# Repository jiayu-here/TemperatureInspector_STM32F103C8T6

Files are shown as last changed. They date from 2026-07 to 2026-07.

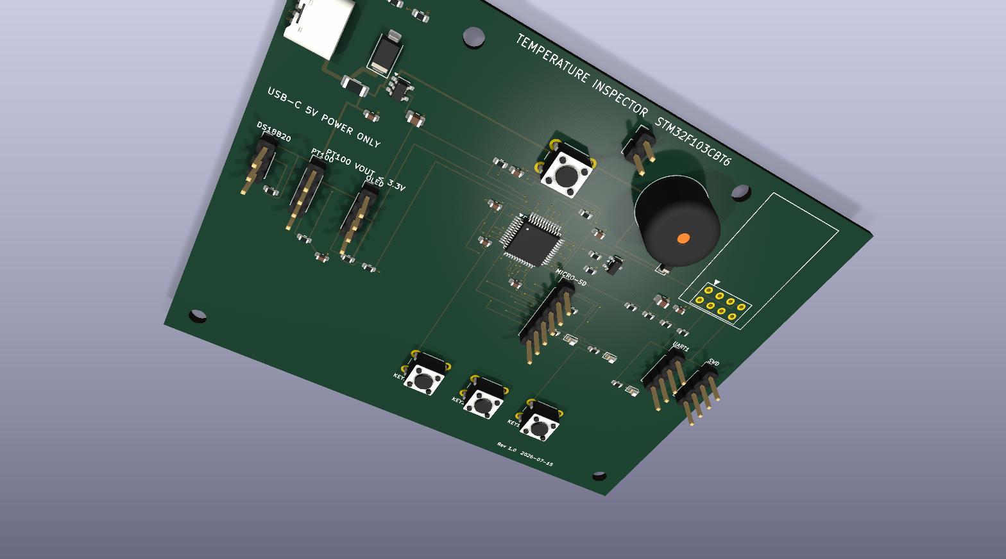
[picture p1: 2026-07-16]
Hardware/KiCad/Preview/PCB_3D_Top.png

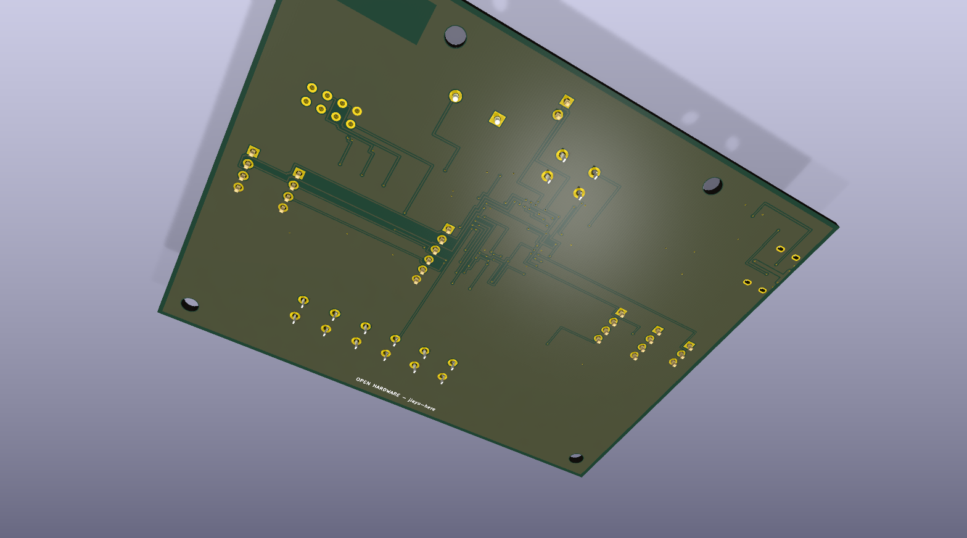
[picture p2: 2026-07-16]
Hardware/KiCad/Preview/PCB_3D_Bottom.png

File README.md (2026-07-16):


# STM32F103C8T6 Temperature Inspector

[English](#english) | [中文](#中文)

This is a temperature-monitoring and alarm project for an STM32F103C8T6 minimum-system board. It integrates DS18B20, PT100 voltage acquisition, OLED, keys, a buzzer, alarm LEDs, SD-card logging through FatFs, serial commands, persistent thresholds, and a reserved ESP-01S cloud-service flow.

## Purpose

The project is designed for embedded temperature-monitoring scenarios. It covers sensor acquisition, data display, alarm decisions, data logging, and serial interaction. It can serve as an STM32 course project, a temperature-acquisition system, a sensor-integration experiment, or an embedded-project portfolio piece.

## Highlights

- Supports both the DS18B20 digital temperature sensor and PT100 analog temperature acquisition.
- OLED displays current temperature, thresholds, alarm status, and system information.
- Supports key configuration, buzzer alarms, and alarm-light indications.
- Uses FatFs to write temperature logs to an SD card.
- Provides serial commands for debugging and parameter inspection.
- Threshold parameters persist across power cycles.
- Reserves an ESP-01S cloud-service flow for future network expansion.
- Supports ST-Link programming and a Keil MDK-compatible project structure.

## Project Entry Points

Main project file:

~~~text
Projects/MDK-ARM/TemperatureInspector_STM32F103C8T6.uvprojx
~~~

Detailed documentation:

~~~text
Docs/工程说明书.md
~~~

Generated HEX file:

~~~text
build_gcc/TemperatureInspector.hex
~~~

## Hardware Design

The repository now includes a complete KiCad 10 schematic and four-layer PCB design. The board uses the pin-compatible `STM32F103CBT6` in LQFP-48, measures 100 mm x 80 mm, and implements the firmware pin map for the sensors, display, storage, alarms, ESP-01S, UART, and SWD interfaces.

- Hardware guide and connector pinout: [`Hardware/KiCad/README_Hardware.md`](Hardware/KiCad/README_Hardware.md)
- KiCad project: `Hardware/KiCad/TemperatureInspector_STM32F103C8T6_Hardware.kicad_pro`
- Manufacturing outputs: `Hardware/KiCad/Manufacturing/`
- Verification reports: `Hardware/KiCad/Verification/` (ERC 0 errors/warnings; DRC 0 violations)
- Ready-to-share archives: `TemperatureInspector_STM32F103C8T6_KiCad_Project.zip` and `TemperatureInspector_STM32F103C8T6_Manufacturing.zip`

## Quick Start

1. Complete wiring using the pin table in Docs/工程说明书.md.
2. Format the SD card as FAT32 and insert it into the SD module.
3. Open Projects/MDK-ARM/TemperatureInspector_STM32F103C8T6.uvprojx in Keil.
4. Connect ST-Link to PA13, PA14, GND, and 3.3 V; keep BOOT0 at 0.
5. Build and download, or directly flash build_gcc/TemperatureInspector.hex.

## Default Parameters

~~~text
Temperature sample period: 15 seconds
Threshold-check period: 15 seconds
SD write period: 15 seconds
DS18B20 default alarm range: below 10 C or above 60 C
PT default alarm range: below 0 C or above 100 C
Cloud service: disabled by default; flow retained in code
Alarm confirmation: alarm after 2 consecutive out-of-range readings
~~~

## Directory Guide

| Directory / file | Purpose |
|---|---|
| Inc/ | Application headers and HAL configuration currently in use |
| Src/ | Application source currently in use |
| Core/ | Synchronized backup of application source and headers |
| Projects/MDK-ARM/ | Keil project |
| Middlewares/Third_Party/FatFs/ | FatFs file-system source |
| Drivers/ | STM32 HAL/CMSIS drivers |
| Docs/ | Project manual, CubeMX configuration, and paper analysis |
| Hardware/KiCad/ | KiCad schematic, PCB, previews, manufacturing files, and ERC/DRC reports |
| build_gcc/ | GCC build output, including flashable HEX |
| TemperatureInspector_STM32F103C8T6.ioc | CubeMX configuration file |

## Suitable Uses

- STM32 embedded-systems course project
- Multi-sensor temperature acquisition and alarm system
- Integrated OLED, SD-card, serial, key, and buzzer experiment
- Keil MDK and STM32 HAL project-structure study

## Notes

- PB3/PB4 are used as keys. Keep debugging in Serial Wire mode; do not enable full JTAG.
- Before powering the board, check power, logic levels, sensor wiring, and SD-card formatting.
- The cloud-service flow is reserved and disabled by default; it can be connected to an actual platform later.

# STM32F103C8T6 温度检测仪

[English](#english) | [中文](#中文)

这是一个基于 STM32F103C8T6 最小系统板的温度检测与报警工程。项目已经接入 DS18B20、PT100 电压采集、OLED、按键、蜂鸣器、报警灯、SD 卡 FatFs 记录、串口命令、阈值掉电保存，以及 ESP-01S 云服务预留流程。

## 项目定位

本项目面向嵌入式温度监测场景，重点覆盖传感器采集、数据显示、报警判断、数据记录和串口交互。它既可以作为 STM32 课程设计，也可以作为温度采集系统、传感器综合实验或嵌入式项目作品展示。

## 功能亮点

- 同时支持 DS18B20 数字温度传感器和 PT100 模拟温度采集。
- OLED 显示当前温度、阈值、报警状态和系统信息。
- 支持按键设置、蜂鸣器报警和报警灯提示。
- 使用 FatFs 将温度记录写入 SD 卡。
- 支持串口命令交互，便于调试和参数查看。
- 阈值参数支持掉电保存。
- 预留 ESP-01S 云服务流程，便于后续扩展联网能力。
- 支持 ST-Link 烧录，工程结构适配 Keil MDK。

## 工程入口

主工程文件：

~~~text
Projects/MDK-ARM/TemperatureInspector_STM32F103C8T6.uvprojx
~~~

详细说明文档：

~~~text
Docs/工程说明书.md
~~~

已生成 HEX：

~~~text
build_gcc/TemperatureInspector.hex
~~~

## 硬件设计

仓库现已包含完整的 KiCad 10 原理图和四层 PCB。板上采用与当前固件引脚兼容的 LQFP-48 `STM32F103CBT6`，板框为 100 mm x 80 mm，已经实现传感器、显示、存储、报警、ESP-01S、串口和 SWD 等接口。

- 硬件说明与接口针序：[`Hardware/KiCad/README_Hardware.md`](Hardware/KiCad/README_Hardware.md)
- KiCad 工程：`Hardware/KiCad/TemperatureInspector_STM32F103C8T6_Hardware.kicad_pro`
- 制造文件：`Hardware/KiCad/Manufacturing/`
- 检查报告：`Hardware/KiCad/Verification/`（ERC 0 错误/警告，DRC 0 违规）
- 可直接交付的压缩包：`TemperatureInspector_STM32F103C8T6_KiCad_Project.zip`、`TemperatureInspector_STM32F103C8T6_Manufacturing.zip`

## 快速使用

1. 按 Docs/工程说明书.md 的引脚表完成接线。
2. 将 SD 卡格式化为 FAT32，并插入 SD 模块。
3. 使用 Keil 打开 Projects/MDK-ARM/TemperatureInspector_STM32F103C8T6.uvprojx。
4. 用 ST-Link 连接 PA13、PA14、GND、3.3V，BOOT0 保持 0。
5. 编译并下载，或直接烧录已生成的 build_gcc/TemperatureInspector.hex。

## 当前默认参数

~~~text
测温周期：15 秒
阈值判断周期：15 秒
SD 写入周期：15 秒
DS18B20 默认报警阈值：低于 10 C 或高于 60 C
PT 默认报警阈值：低于 0 C 或高于 100 C
云服务：默认关闭，代码流程保留
报警确认：连续 2 次超阈值才报警
~~~

## 目录说明

| 目录/文件 | 作用 |
|---|---|
| Inc/ | 当前实际使用的应用头文件和 HAL 配置 |
| Src/ | 当前实际使用的应用源码 |
| Core/ | 同步备份的应用源码/头文件 |
| Projects/MDK-ARM/ | Keil 工程 |
| Middlewares/Third_Party/FatFs/ | FatFs 文件系统源码 |
| Drivers/ | STM32 HAL/CMSIS 驱动 |
| Docs/ | 工程说明、CubeMX 配置、论文分析 |
| Hardware/KiCad/ | KiCad 原理图、PCB、预览图、制造文件和 ERC/DRC 报告 |
| build_gcc/ | GCC 编译输出，含可烧录 HEX |
| TemperatureInspector_STM32F103C8T6.ioc | CubeMX 配置文件 |

## 适用场景

- STM32 嵌入式课程设计。
- 多传感器温度采集与报警系统。
- OLED、SD 卡、串口、按键和蜂鸣器综合实验。
- Keil MDK + STM32 HAL 工程结构学习。

## 注意事项

- PB3/PB4 用作按键，所以调试方式必须保持 Serial Wire，不要启用完整 JTAG。
- 上板前建议先检查供电、电平、传感器接线和 SD 卡格式。
- 云服务流程目前为预留状态，默认关闭，后续可继续接入实际平台。

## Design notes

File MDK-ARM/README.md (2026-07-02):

# Keil Project

Generate the real Keil project from CubeMX:

1. Open `../TemperatureInspector_STM32F103C8T6.ioc`.
2. Set `Toolchain / IDE` to `MDK-ARM`.
3. Click `GENERATE CODE`.
4. CubeMX will create `TemperatureInspector.uvprojx` here.
5. Open it with Keil.

The application code is in:

- `../Core/Inc/app_*.h`
- `../Core/Src/app_*.c`

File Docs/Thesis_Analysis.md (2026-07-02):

# Thesis Analysis And Implementation Mapping

Appendix was not used. The implementation is based on the main thesis body and your confirmed hardware.

## Confirmed Hardware

- Board: STM32F103C8T6 green board
- Display: 4-pin I2C OLED
- WiFi: ESP-01S
- Storage: 6-pin SPI MicroSD module
- PT100 interface: voltage output to STM32 ADC
- Download/debug method: ST-Link SWD
- DS18B20 alarm rule: below 10 C or above 60 C
- PT100 alarm rule: below 0 C or above 100 C

## Thesis Requirements Mapped To Code

- Real-time temperature inspection: `app.c`
- DS18B20 temperature acquisition: `app_ds18b20.c`
- PT100 temperature acquisition through ADC linear formula `temperature = 51.2 * voltage`: `app_pt100.c`
- OLED local display: `app_oled.c`
- LED + buzzer alarm: `app_alarm.c`
- SD card historical data storage: `app_storage.c`
- ESP8266/ESP-01S WiFi remote upload: `app_esp8266.c`
- OneNET MQTT upload: minimal MQTT packet build in `app_esp8266.c`
- Three buttons for independent DS18B20/PT100 threshold adjustment and switching: `app_keys.c`

## Thesis Pins Preserved

- MCU: STM32F103C8T6
- USART1 optional debug UART: PA9 TX, PA10 RX
- ST-Link SWD:
  - SWDIO: PA13
  - SWCLK: PA14
- DS18B20 data pin: PA0
- SD card SPI2:
  - CS: PB12
  - SCK: PB13
  - MISO: PB14
  - MOSI: PB15

## Pins Reassigned For Your Actual Modules

- PT100 voltage input:
  - ADC: PA1 / ADC1_IN1
- Keys:
  - K1: PB3
  - K2: PB4
  - K3: PB5
- OLED I2C1:
  - SCL: PB6
  - SDA: PB7
- ESP-01S USART2:
  - STM32 TX: PA2
  - STM32 RX: PA3
- Buzzer: PB0
- Alarm LED: PB1
- Board LED: PC13

## Calibration Items

- PT100 conversion uses your provided relation: `temperature = 51.2 * voltage`.
- ADC reference is set to 3.3 V in `PT100_ADC_VREF`.
- If measured temperature is off, adjust `PT100_TEMP_PER_VOLT` in `app_config.h`.

## OneNET Items Still Needed

Fill these in `app_config.h` before expecting cloud upload:

- `WIFI_SSID`
- `WIFI_PASSWORD`
- `ONENET_PRODUCT_ID`
- `ONENET_DEVICE_NAME`
- `ONENET_DEVICE_TOKEN`

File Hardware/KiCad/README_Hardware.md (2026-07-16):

# 温度检测仪硬件交付说明

本目录是 `TemperatureInspector_STM32F103C8T6` 的 KiCad 10 硬件工程。主控采用与现有 CubeMX/固件引脚兼容的 `STM32F103CBT6`（LQFP-48）。

- GitHub 工程：<https://github.com/jiayu-here/TemperatureInspector_STM32F103C8T6>
- KiCad 工程：`TemperatureInspector_STM32F103C8T6_Hardware.kicad_pro`
- 原理图：`TemperatureInspector_STM32F103C8T6_Hardware.kicad_sch`
- PCB：`TemperatureInspector_STM32F103C8T6_Hardware.kicad_pcb`
- 原理图 PDF：`Documentation/Schematic.pdf`

## 1. 电路功能

- USB-C 仅作为 5 V 供电输入，不连接 USB 数据线。
- AP2112K-3.3 将 5 V 转换为 3.3 V。
- DS18B20 数字温度采集。
- PT100 模块模拟电压采集，板上提供 1 kΩ + 100 nF RC 滤波。
- OLED、Micro-SD、ESP-01S、UART1、SWD 接口。
- 3 个按键、复位键、有源蜂鸣器、报警灯、运行灯和电源灯。

## 2. 接口针序

### J1 - USB-C 电源

USB-C 5 V 电源输入；CC1/CC2 各使用 5.1 kΩ 下拉。封装选用电源专用的 `GCT USB4125 6P`，与原理图电源引脚一一对应。该接口不支持 USB 数据通信，也不实现 USB-PD 协议。

### J2 - DS18B20

| 引脚 | 信号 | MCU |
|---|---|---|
| 1 | 3V3 | - |
| 2 | DS18B20_DQ | PA0 |
| 3 | GND | - |

### J3 - PT100 模块

| 引脚 | 信号 | MCU/说明 |
|---|---|---|
| 1 | 5V | 模块电源 |
| 2 | 3V3 | 备用 3.3 V 电源 |
| 3 | PT100_RAW/VOUT | 经 1 kΩ + 100 nF 滤波后进入 PA1/ADC1_IN1 |
| 4 | GND | - |

PT100 模块的 VOUT 必须保持在 0-3.3 V 范围内，禁止将 5 V 模拟电压直接送入 PA1。

### J4 - OLED（I2C）

| 引脚 | 信号 | MCU |
|---|---|---|
| 1 | GND | - |
| 2 | 3V3 | - |
| 3 | I2C_SCL | PB6 |
| 4 | I2C_SDA | PB7 |

### J5 - Micro-SD（SPI2）

| 引脚 | 信号 | MCU |
|---|---|---|
| 1 | 3V3 | - |
| 2 | SD_CS | PB12 |
| 3 | SD_SCK | PB13 |
| 4 | SD_MISO | PB14 |
| 5 | SD_MOSI | PB15 |
| 6 | GND | - |

### J6 - 调试串口（USART1）

| 引脚 | 信号 | MCU |
|---|---|---|
| 1 | 3V3 | - |
| 2 | DEBUG_TX | PA9/USART1_TX |
| 3 | DEBUG_RX | PA10/USART1_RX |
| 4 | GND | - |

### J7 - SWD

| 引脚 | 信号 | MCU |
|---|---|---|
| 1 | 3V3 | 目标板电平参考 |
| 2 | SWDIO | PA13 |
| 3 | SWCLK | PA14 |
| 4 | GND | - |

### JP1 - BOOT0

| 引脚 | 信号 |
|---|---|
| 1 | 3V3 |
| 2 | BOOT0 |

正常运行时 JP1 保持断开，R4 将 BOOT0 下拉。需要进入 STM32 ROM Bootloader 时再短接 JP1。

## 3. 固件引脚映射

| 功能 | MCU 引脚 |
|---|---|
| DS18B20 | PA0 |
| PT100 ADC | PA1 |
| ESP-01S UART TX/RX | PA2/PA3（USART2） |
| 调试 UART TX/RX | PA9/PA10（USART1） |
| SWDIO/SWCLK | PA13/PA14 |
| 蜂鸣器 | PB0 |
| 报警灯 | PB1 |
| KEY1/KEY2/KEY3 | PB3/PB4/PB5 |
| OLED SCL/SDA | PB6/PB7（I2C1） |
| SD CS/SCK/MISO/MOSI | PB12/PB13/PB14/PB15（SPI2） |
| 运行灯 | PC13 |

PB3/PB4 已作为按键使用，调试模式必须保持 Serial Wire，不能启用完整 JTAG。

## 4. PCB 与层叠

- 板框：100 mm × 80 mm。
- 板厚：1.6 mm。
- 4 层铜：
  - L1 / F.Cu：元件和信号。
  - L2 / In1.Cu：整面 GND。
  - L3 / In2.Cu：整面 3V3。
  - L4 / B.Cu：信号和 GND 辅助覆铜。
- 4 个 M3 安装孔。
- 推荐制造材料：常规 FR-4；具体介质厚度和铜厚由板厂按其标准 4 层 1.6 mm 叠层确认。

## 5. 设计规则

| 项目 | 设置 |
|---|---|
| 默认/最小线宽 | 0.18 mm |
| 最小铜间距 | 0.15 mm |
| 铜到板边 | 0.30 mm |
| 默认过孔 | 0.40/0.20 mm（外径/钻孔） |
| USB_5V 主干 | 0.60 mm |
| +5V 支路 | 0.30 mm |
| 差分线宽/间距 | 0.18/0.18 mm |
| 差分过孔间距 | 0.18 mm |

USB-C 为纯供电接口，所以当前 PCB 没有实际 USB 差分对；差分规则已保留供后续扩展使用。

## 6. ERC/DRC 验证

最终 KiCad 10.0.4 检查结果：

- ERC：0 Errors，0 Warnings。
- DRC：0 Violations。
- 未连接焊盘：0。
- 封装错误：0。

报告位于：

- `Verification/erc.rpt`
- `Verification/erc.json`
- `Verification/drc.rpt`
- `Verification/drc.json`

## 7. 制造文件

`Manufacturing` 目录包含：

- `Gerber/`：11 个制板层 Gerber 文件和 `.gbrjob` 作业文件。
- `Drill/`：PTH/NPTH Excellon 钻孔文件、钻孔图和钻孔报告。
- `BOM.csv`：物料清单。
- `Component_Positions_All.csv`：全部元件坐标。
- `PickPlace_SMD.csv`：SMD 贴片坐标。

Gerber 使用 KiCad 扩展名 `.gbr`。下单时将 `Gerber` 和 `Drill` 一并交给板厂；贴片时再提供 BOM 和坐标文件。

## 8. 上电与生产注意事项

1. 首次上电前检查 USB 5 V、3.3 V 和 GND 是否短路。
2. 所有外设逻辑电平必须为 3.3 V。
3. PT100 模块输出不得超过 3.3 V。
4. ESP-01S 瞬时电流较大，实际装配时确认 AP2112K、USB 电源和去耦满足峰值电流。
5. ESP-01S 在 3D 预览中没有完整器件模型，只显示焊盘和天线禁布区；不影响 PCB 制造文件。
6. ERC/DRC 通过只代表规则检查通过。批量生产前仍应先打样、实测电源和各接口，再让板厂执行 DFM 检查。

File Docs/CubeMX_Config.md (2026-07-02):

# CubeMX Configuration

Open CubeMX and configure these items for STM32F103C8T6.

## Project Manager

- Project Name: `TemperatureInspector`
- Toolchain / IDE: `MDK-ARM`
- Generate peripheral initialization as pair of `.c/.h` files: optional

## System Core

- SYS:
  - Debug: `Serial Wire`. This disables full JTAG and keeps PB3/PB4 usable for keys.
- RCC:
  - HSE: `Crystal/Ceramic Resonator`
  - LSE: optional. Enable only if your board has 32.768 kHz crystal.
- Clock:
  - HSE: 8 MHz
  - SYSCLK: 72 MHz
  - AHB: 72 MHz
  - APB1: 36 MHz
  - APB2: 72 MHz

## GPIO

- PA0: GPIO output, DS18B20 DQ. The driver switches input/output dynamically.
- PA1: ADC1_IN1, PT100 voltage input. Formula: `temperature = 51.2 * voltage`.
- PB3, PB4, PB5: GPIO input, Pull-up, keys.
- PB0: GPIO output, buzzer.
- PB1: GPIO output, alarm LED.
- PB12: GPIO output, SD CS, default high.
- PC13: GPIO output, board status LED.

## I2C

- I2C1:
  - PB6: SCL
  - PB7: SDA
  - Speed: 100 kHz
  - OLED address: usually `0x3C`

## SPI

## ADC

- ADC1:
  - IN1 on PA1
  - Resolution: 12 bit
  - Continuous Conversion: Disabled
  - External Trigger: Software start
  - Sampling time: 55.5 cycles or longer

- SPI2:
  - PB13: SCK
  - PB14: MISO
  - PB15: MOSI
  - Mode: Full-Duplex Master
  - Data Size: 8 bit
  - CPOL: Low
  - CPHA: 1 Edge
  - NSS: Software
  - Prescaler: start slow, e.g. 256 for init, then faster if your SD driver supports it

## USART

- USART1:
  - PA9 TX, PA10 RX
  - 115200 8N1
  - Optional debug printf UART. Firmware download/debug uses ST-Link SWD, not USART1.

- USART2:
  - PA2 TX, PA3 RX
  - 115200 8N1
  - ESP8266 AT command interface

## Middleware

- FATFS:
  - Enable User-defined or SPI SD card mode depending on CubeMX version.
  - If CubeMX does not provide SPI SD glue automatically, keep FatFs disabled first and use the project without SD logging, then add SD diskio later.

## Required User Code Calls

In generated `main.c`:

```c
#include "app.h"

int main(void)
{
    HAL_Init();
    SystemClock_Config();
    MX_GPIO_Init();
    MX_ADC1_Init();
    MX_I2C1_Init();
    MX_SPI2_Init();
    MX_USART1_UART_Init();
    MX_USART2_UART_Init();
    MX_FATFS_Init();

    App_Init();

    while (1)
    {
        App_Loop();
    }
}
```

## ST-Link Download Settings

In Keil:

- `Options for Target` -> `Debug` -> choose `ST-Link Debugger`.
- `Settings` -> Port: `SW`.
- `Flash Download` -> enable `Reset and Run` if you want the program to start after download.

Hardware wiring:

- ST-Link `SWDIO` -> board `SWDIO / PA13`
- ST-Link `SWCLK` -> board `SWCLK / PA14`
- ST-Link `GND` -> board `GND`
- ST-Link `3.3V` -> board `3.3V` only when you power the board from ST-Link
- Keep `BOOT0 = 0`

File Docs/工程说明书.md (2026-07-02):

# STM32F103C8T6 温度检测报警工程说明书

## 1. 工程概述

本工程用于 STM32F103C8T6 最小系统板，实现双路温度检测、阈值报警、OLED 显示、SD 卡记录、串口调参、阈值掉电保存和云服务预留。

核心功能：

- DS18B20 数字温度采集
- PT100 电压采集，按 `温度 = 51.2 * 电压` 换算
- OLED 实时显示温度、阈值、报警状态、SD 状态、最高/最低温
- 蜂鸣器和 LED 声光报警
- 三个按键调节 DS/PT 各自上下阈值
- 报警可手动静音
- 连续 2 次超阈值才报警，降低误报警
- SD 卡 FatFs 记录 CSV 文件
- SD 写入失败计数显示
- 阈值保存到 STM32 内部 Flash，断电不丢失
- 串口命令读取状态、设置阈值、恢复默认、静音
- ESP-01S 云服务流程保留，默认关闭
- 云上传失败时预留 SD 离线缓存流程

## 2. 硬件清单

| 硬件 | 说明 |
|---|---|
| STM32F103C8T6 最小系统板 | 俗称绿板/蓝板均可，按本文引脚连接 |
| ST-Link | 用 SWD 下载和调试 |
| 0.96 寸 SSD1306 OLED | 4 针 I2C，常见地址 0x3C |
| DS18B20 | 单总线数字温度传感器 |
| PT100 电压转换模块 | 输出电压接 ADC，公式为 `T = 51.2 * V` |
| SD 卡 SPI 模块 | 6 针模块，使用 SPI2 |
| ESP-01S | 云服务预留，默认关闭 |
| 有源蜂鸣器 | 高电平响，接 PB0 |
| LED 或报警灯模块 | 高电平亮，接 PB1 |
| 3 个按键 | 低电平按下，使用内部上拉 |

## 3. 完整引脚表

| 模块 | 模块信号 | STM32 引脚 | STM32 功能 | 说明 |
|---|---|---|---|---|
| DS18B20 | DQ | PA0 | GPIO | 需要 4.7k 上拉到 3.3V |
| PT100 电压模块 | AO/VOUT | PA1 | ADC1_IN1 | 输入电压不能超过 3.3V |
| ESP-01S | RX | PA2 | USART2_TX | STM32 发给 ESP |
| ESP-01S | TX | PA3 | USART2_RX | ESP 发给 STM32 |
| 蜂鸣器 | IN | PB0 | GPIO Output | 高电平响 |
| 报警灯 | IN | PB1 | GPIO Output | 高电平亮 |
| 按键 1 | K1 | PB3 | GPIO Input Pull-up | 当前阈值减小 |
| 按键 2 | K2 | PB4 | GPIO Input Pull-up | 当前阈值增大 |
| 按键 3 | K3 | PB5 | GPIO Input Pull-up | 切换当前阈值 |
| OLED | SCL | PB6 | I2C1_SCL | I2C 时钟 |
| OLED | SDA | PB7 | I2C1_SDA | I2C 数据 |
| SD 卡模块 | CS | PB12 | GPIO Output | 片选，默认高 |
| SD 卡模块 | SCK | PB13 | SPI2_SCK | SPI 时钟 |
| SD 卡模块 | MISO/DO | PB14 | SPI2_MISO | SD 到 STM32 |
| SD 卡模块 | MOSI/DI | PB15 | SPI2_MOSI | STM32 到 SD |
| 串口调试 | TX | PA9 | USART1_TX | 连接 USB-TTL RX |
| 串口调试 | RX | PA10 | USART1_RX | 连接 USB-TTL TX |
| ST-Link | SWDIO | PA13 | SWDIO | 下载/调试 |
| ST-Link | SWCLK | PA14 | SWCLK | 下载/调试 |
| 板载 LED | LED | PC13 | GPIO Output | 心跳灯 |

注意：

- PB3/PB4 默认属于 JTAG 引脚，本工程已关闭 JTAG，只保留 SWD。因此 CubeMX/Keil 中 Debug 必须选 `Serial Wire`。
- 所有模块必须共地。
- PT100 模块输出必须确认不超过 3.3V，否则会损坏 STM32 ADC。
- ESP-01S 必须使用 3.3V 供电，电流能力要足够。

## 4. OLED 显示说明

正常运行时 OLED 8 行含义如下：

```text
DS:+025.3C
PT:+051.2C
DSL:010 DSH:060
PTL:000 PTH:100
DA:0 PA:0 AL:0
M:0 DSL SD:1 E:0
D:024/026
P:050/053
```

逐行解释：

| 行 | 示例 | 含义 |
|---|---|---|
| 1 | `DS:+025.3C` | DS18B20 当前温度；`DS:ERR` 表示读取失败 |
| 2 | `PT:+051.2C` | PT 电压换算温度 |
| 3 | `DSL:010 DSH:060` | DS18B20 低阈值/高阈值 |
| 4 | `PTL:000 PTH:100` | PT 低阈值/高阈值 |
| 5 | `DA:0 PA:0 AL:0` | DS 报警/PT 报警/总报警 |
| 6 | `M:0 DSL SD:1 E:0` | 静音状态/当前调节项/SD 状态/SD 错误次数 |
| 7 | `D:024/026` | DS18B20 开机后的最低/最高温 |
| 8 | `P:050/053` | PT 开机后的最低/最高温 |

状态含义：

- `DA:1`：DS18B20 连续 2 次超阈值
- `PA:1`：PT 连续 2 次超阈值
- `AL:1`：总报警成立
- `M:1`：报警已手动静音
- `SD:1`：SD 卡正常
- `SD:0`：SD 卡未挂载或写入失败
- `E:n`：SD 写入失败次数
- `WF:0`：云服务关闭或未连接；当前默认关闭

OLED 采用“内容变化才刷新”的方式，正常不会快速闪屏。

## 5. 按键使用说明

三个按键均为低电平按下。

| 操作 | 功能 |
|---|---|
| `KEY3` 短按 | 切换当前调节项：`DSL -> DSH -> PTL -> PTH` |
| `KEY1` 短按 | 当前阈值减小 1 C |
| `KEY2` 短按 | 当前阈值增大 1 C |
| `KEY1` 长按 | 超过 1 秒后连续减小，每 250 ms 一次 |
| `KEY2` 长按 | 超过 1 秒后连续增大，每 250 ms 一次 |
| `KEY1 + KEY2` 同时按 | 报警静音/恢复 |

阈值说明：

- `DSL`：DS18B20 低温报警阈值
- `DSH`：DS18B20 高温报警阈值
- `PTL`：PT 低温报警阈值
- `PTH`：PT 高温报警阈值

阈值改动后会自动保存到 STM32 内部 Flash，断电后仍然保留。

## 6. 串口命令说明

USART1 用于串口调试：

- PA9：STM32 TX，接 USB-TTL RX
- PA10：STM32 RX，接 USB-TTL TX
- 波特率：115200
- 数据格式：8N1

支持命令：

```text
GET
SET DSL 10
SET DSH 60
SET PTL 0
SET PTH 100
RESET
MUTE
```

命令说明：

| 命令 | 功能 |
|---|---|
| `GET` | 查看当前阈值、SD 状态、报警状态 |
| `SET DSL 10` | 设置 DS18B20 低阈值为 10 C |
| `SET DSH 60` | 设置 DS18B20 高阈值为 60 C |
| `SET PTL 0` | 设置 PT 低阈值为 0 C |
| `SET PTH 100` | 设置 PT 高阈值为 100 C |
| `RESET` | 恢复默认阈值并保存 |
| `MUTE` | 报警静音/恢复 |

## 7. SD 卡记录说明

SD 卡使用 SPI2 + FatFs。

接线：

| SD 模块 | STM32 |
|---|---|
| CS | PB12 |
| SCK | PB13 |
| MISO/DO | PB14 |
| MOSI/DI | PB15 |
| VCC | 3.3V |
| GND | GND |

使用要求：

- SD 卡建议格式化为 FAT32。
- 上电前插入 SD 卡。
- 若 OLED 显示 `SD:0`，检查接线、电源、格式化和卡座接触。

日志文件：

```text
temp_log.csv
```

首次创建文件时会自动写表头：

```text
time_ms,ds18b20,pt100,ds_low,ds_high,pt_low,pt_high,ds_alarm,pt_alarm,alarm
```

记录周期：15 秒。

云服务离线缓存文件：

```text
cloud_cache.csv
```

当前云服务默认关闭，所以正常不会生成该文件。以后开启云服务后，如果上传失败，会把待上传数据缓存到该文件。

## 8. 报警逻辑

采样周期：15 秒。

判断逻辑：

1. 每 15 秒读取 DS18B20 和 PT。
2. 判断是否低于低阈值或高于高阈值。
3. 同一路温度连续 2 次超阈值，才认为报警成立。
4. 任一路报警成立，总报警 `AL` 置 1。
5. 总报警成立且未静音时，蜂鸣器和报警灯按节奏闪烁/鸣响。
6. 温度恢复正常后，报警和静音状态自动清除。

## 9. 云服务说明

ESP-01S 云服务代码已经保留，但默认关闭：

```c
#define APP_ENABLE_WIFI 0
```

配置文件：

```text
Inc/app_config.h
```

如需开启，需要填写：

```c
WIFI_SSID
WIFI_PASSWORD
ONENET_PRODUCT_ID
ONENET_DEVICE_NAME
ONENET_DEVICE_TOKEN
```

然后把：

```c
#define APP_ENABLE_WIFI 0
```

改成：

```c
#define APP_ENABLE_WIFI 1
```

云服务流程：

1. `ESP8266_Init()` 初始化 ESP-01S。
2. 连接 WiFi。
3. 连接 OneNET MQTT。
4. 每 15 秒调用 `ESP8266_Upload()` 上传温度和报警状态。
5. 如果上传失败，写入 SD 卡 `cloud_cache.csv`。
6. 网络恢复并上传成功后，清除缓存文件。

注意：ESP-01S 必须使用稳定 3.3V 电源，不建议直接从普通 USB-TTL 小电流 3.3V 脚供电。

## 10. CubeMX 配置要点

MCU：`STM32F103C8T6`

System Core：

- SYS Debug：`Serial Wire`
- RCC：HSE 8 MHz
- SYSCLK：72 MHz

外设：

- ADC1_IN1：PA1
- I2C1：PB6/PB7，100 kHz
- SPI2：PB13/PB14/PB15，Master，8 bit，CPOL Low，CPHA 1 Edge，NSS Software
- USART1：PA9/PA10，115200
- USART2：PA2/PA3，115200
- GPIO：按本文引脚表配置

FatFs：

- 本工程已经内置 FatFs 和 SPI SD 底层驱动。
- 不依赖 CubeMX 自动生成 `fatfs.c`。
- 重新生成 CubeMX 代码后，需要保留 `Middlewares/Third_Party/FatFs` 和 `Src/app_storage.c`。

## 11. Keil 使用说明

工程文件：

```text
Projects/MDK-ARM/TemperatureInspector_STM32F103C8T6.uvprojx
```

Keil 设置：

- Device：STM32F103C8
- Debug：ST-Link Debugger
- Port：SW
- Flash Download：Reset and Run

如果 Keil 弹出：

```text
Project File has been modified externally, Reload?
```

选择 `Yes`。

## 12. VS Code 使用说明

VS Code 主要用于看代码和编辑代码。

建议打开整个工程根目录，例如本项目文件夹：

```text
TemperatureInspector_STM32F103C8T6
```

主要看这些文件：

| 文件 | 作用 |
|---|---|
| `Inc/app_config.h` | 引脚、周期、默认阈值、WiFi 配置 |
| `Src/app.c` | 主业务逻辑 |
| `Src/app_oled.c` | OLED 显示 |
| `Src/app_storage.c` | SD 卡记录 |
| `Src/app_ds18b20.c` | DS18B20 驱动 |
| `Src/app_pt100.c` | PT 温度换算 |
| `Src/app_esp8266.c` | ESP-01S/OneNET 流程 |
| `Src/app_settings.c` | 阈值 Flash 保存 |

## 13. ST-Link 烧录说明

接线：

| ST-Link | STM32 |
|---|---|
| SWDIO | PA13/SWDIO |
| SWCLK | PA14/SWCLK |
| GND | GND |
| 3.3V | 3.3V，可选，取决于供电方式 |

BOOT0 保持 `0`。

可烧录文件：

```text
build_gcc/TemperatureInspector.hex
```

也可以在 Keil 中编译后下载。

## 14. 工程目录说明

| 路径 | 说明 |
|---|---|
| `Inc/` | 当前实际使用的头文件 |
| `Src/` | 当前实际使用的源文件 |
| `Core/` | 同步备份代码 |
| `Drivers/` | STM32 HAL/CMSIS 驱动 |
| `Middlewares/Third_Party/FatFs/` | FatFs 文件系统 |
| `Projects/MDK-ARM/` | Keil 工程 |
| `Docs/` | 文档 |
| `build_gcc/` | GCC 输出，含 HEX |
| `TemperatureInspector_STM32F103C8T6.ioc` | CubeMX 工程 |

## 15. 常见问题

### OLED 不显示

- 检查 OLED 地址是否为 0x3C。
- 检查 PB6/PB7 是否接反。
- 检查 OLED 电源和 GND。

### DS 显示 ERR

- 检查 PA0 接线。
- 检查 DS18B20 是否有 4.7k 上拉到 3.3V。
- 检查 DS18B20 电源方向。

### PT 温度不对

- 用万用表测 PA1 输入电压。
- 当前公式是 `T = 51.2 * V`。
- 例如 PA1 是 1.00V，则显示约 51.2 C。
- PA1 电压不能超过 3.3V。

### SD:0 或 E 变大

- SD 卡格式化为 FAT32。
- 检查 PB12/PB13/PB14/PB15。
- 检查 SD 模块是否支持 3.3V 逻辑。
- 重新插卡后按复位。

### 蜂鸣器一直响

- 查看 OLED 的 `DA/PA/AL`。
- 若 `AL:1`，说明连续 2 次超阈值。
- 可按 `KEY1 + KEY2` 静音。
- 检查阈值是否设置过低/过高。

### 按键没反应

- 按键一端接 GPIO，一端接 GND。
- 工程使用内部上拉，所以按下应为低电平。
- PB3/PB4 需要关闭 JTAG，只保留 SWD。

## 16. 交付状态

本工程已经完成：

- 源码整理
- 关键源码中文注释
- FatFs/SD 底层驱动接入
- Keil 工程源文件加入
- ST-Link 烧录验证
- OLED 内容变化才刷新
- 阈值 Flash 保存
- 串口命令
- 开机自检
- SD CSV 记录
- 云服务预留流程

别人拿到工程后，按本文接线并烧录 `build_gcc/TemperatureInspector.hex` 即可运行。

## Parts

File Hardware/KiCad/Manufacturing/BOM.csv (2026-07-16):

Reference | Value | Footprint | Quantity
BZ1 | 5V ACTIVE BUZZER | Buzzer_Beeper:Buzzer_12x9.5RM7.6 | 1
C1 | 1u | Capacitor_SMD:C_0603_1608Metric | 1
C2 | 4.7u | Capacitor_SMD:C_0805_2012Metric | 1
C3-C5,C7,C8,C10 | 100n | Capacitor_SMD:C_0603_1608Metric | 6
C6 | 1u VDDA | Capacitor_SMD:C_0603_1608Metric | 1
C9 | 10u | Capacitor_SMD:C_0805_2012Metric | 1
D1 | SMBJ5.0A | Diode_SMD:D_SMA | 1
D2 | 1N4148 | Diode_SMD:D_SOD-123 | 1
D3 | ALARM RED | LED_SMD:LED_0603_1608Metric | 1
D4 | HEARTBEAT GREEN | LED_SMD:LED_0603_1608Metric | 1
D5 | POWER GREEN | LED_SMD:LED_0603_1608Metric | 1
F1 | 1A PTC | Fuse:Fuse_1206_3216Metric | 1
J1 | USB-C 5V POWER ONLY | Connector_USB:USB_C_Receptacle_GCT_USB4125-xx-x_6P_TopMnt_Horizontal | 1
J2 | DS18B20: 3V3,DQ,GND | Connector_PinHeader_2.54mm:PinHeader_1x03_P2.54mm_Vertical | 1
J3 | PT100: 5V,3V3,VOUT,GND | Connector_PinHeader_2.54mm:PinHeader_1x04_P2.54mm_Vertical | 1
J4 | OLED: GND,3V3,SCL,SDA | Connector_PinHeader_2.54mm:PinHeader_1x04_P2.54mm_Vertical | 1
J5 | SD: 3V3,CS,SCK,MISO,MOSI,GND | Connector_PinHeader_2.54mm:PinHeader_1x06_P2.54mm_Vertical | 1
J6 | UART1: 3V3,TX,RX,GND | Connector_PinHeader_2.54mm:PinHeader_1x04_P2.54mm_Vertical | 1
J7 | SWD: 3V3,SWDIO,SWCLK,GND | Connector_PinHeader_2.54mm:PinHeader_1x04_P2.54mm_Vertical | 1
JP1 | BOOT0 | Connector_PinHeader_2.54mm:PinHeader_1x02_P2.54mm_Vertical | 1
Q1 | MMBT3904 | Package_TO_SOT_SMD:SOT-23 | 1
R1,R2 | 5.1k | Resistor_SMD:R_0603_1608Metric | 2
R3,R4,R9-R13 | 10k | Resistor_SMD:R_0603_1608Metric | 7
R5,R7,R8 | 4.7k | Resistor_SMD:R_0603_1608Metric | 3
R6,R14,R16,R18 | 1k | Resistor_SMD:R_0603_1608Metric | 4
R15 | 100k | Resistor_SMD:R_0603_1608Metric | 1
R17 | 2.2k | Resistor_SMD:R_0603_1608Metric | 1
SW1 | KEY1 | Button_Switch_THT:SW_PUSH_6mm | 1
SW2 | KEY2 | Button_Switch_THT:SW_PUSH_6mm | 1
SW3 | KEY3 | Button_Switch_THT:SW_PUSH_6mm | 1
SW4 | RESET | Button_Switch_THT:SW_PUSH_6mm | 1
U1 | STM32F103CBT6 | Package_QFP:LQFP-48_7x7mm_P0.5mm | 1
U2 | AP2112K-3.3 | Package_TO_SOT_SMD:SOT-23-5 | 1
U3 | ESP-01S | RF_Module:ESP-01 | 1

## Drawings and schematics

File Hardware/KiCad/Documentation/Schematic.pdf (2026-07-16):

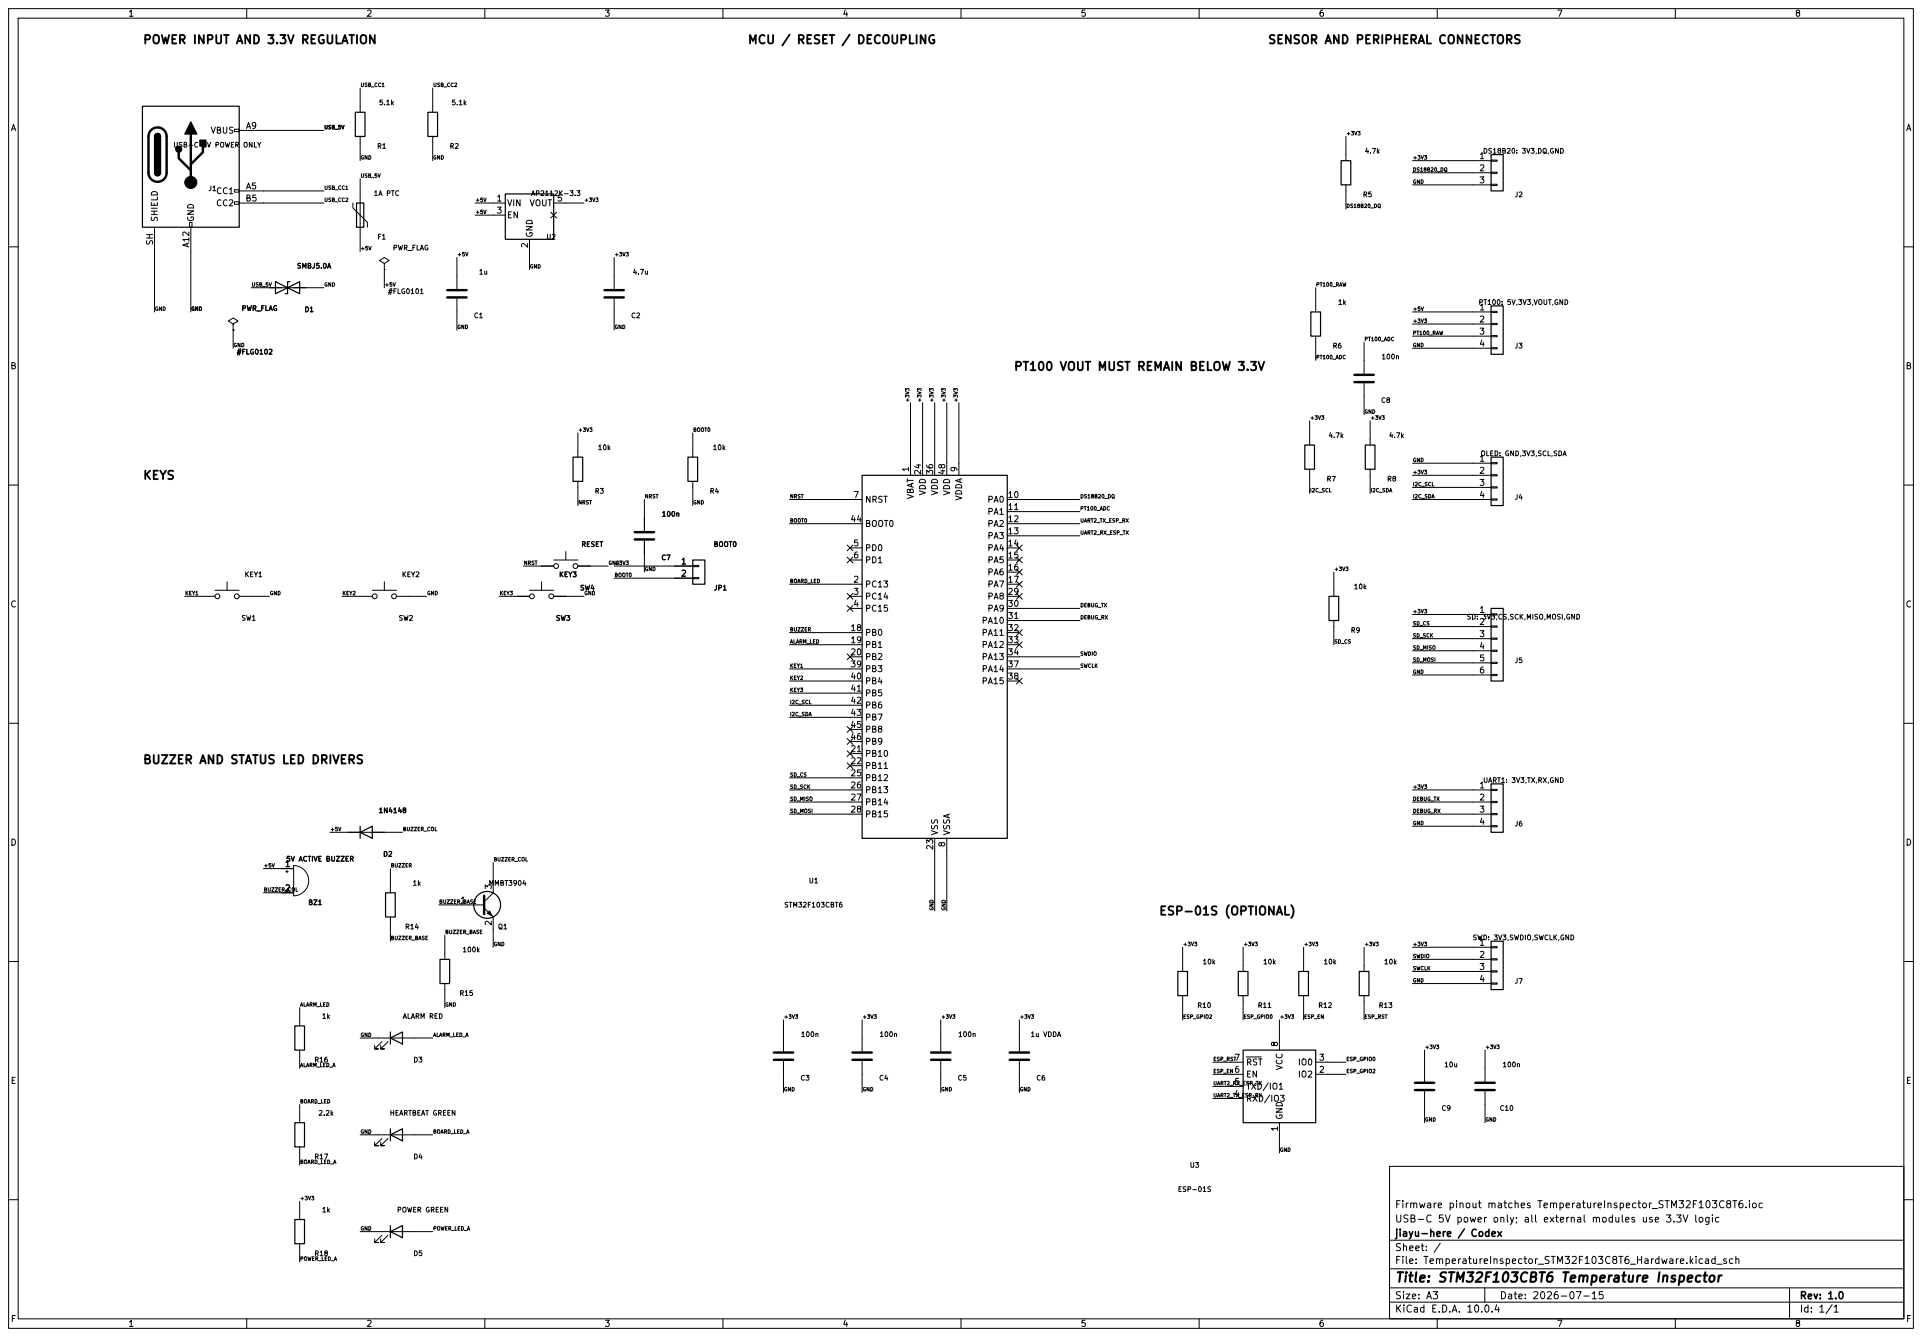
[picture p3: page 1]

POWER INPUT AND 3.3V REGULATION

PT100 VOUT MUST REMAIN BELOW 3.3V

SD: 3V3,CS,SCK,MISO,MOSI,GND 1

BUZZER AND STATUS LED DRIVERS

Firmware pinout matches TemperatureInspector_STM32F103C8T6.ioc
USB-C 5V power only; all external modules use 3.3V logic
jiayu-here / Codex
Sheet: /
File: TemperatureInspector_STM32F103C8T6_Hardware.kicad_sch
Title: STM32F103CBT6 Temperature Inspector

Size: A3 | Rev: 1.0 | F Date: 2026-07-15
KiCad E.D.A. 10.0.4 | Id: 1/1

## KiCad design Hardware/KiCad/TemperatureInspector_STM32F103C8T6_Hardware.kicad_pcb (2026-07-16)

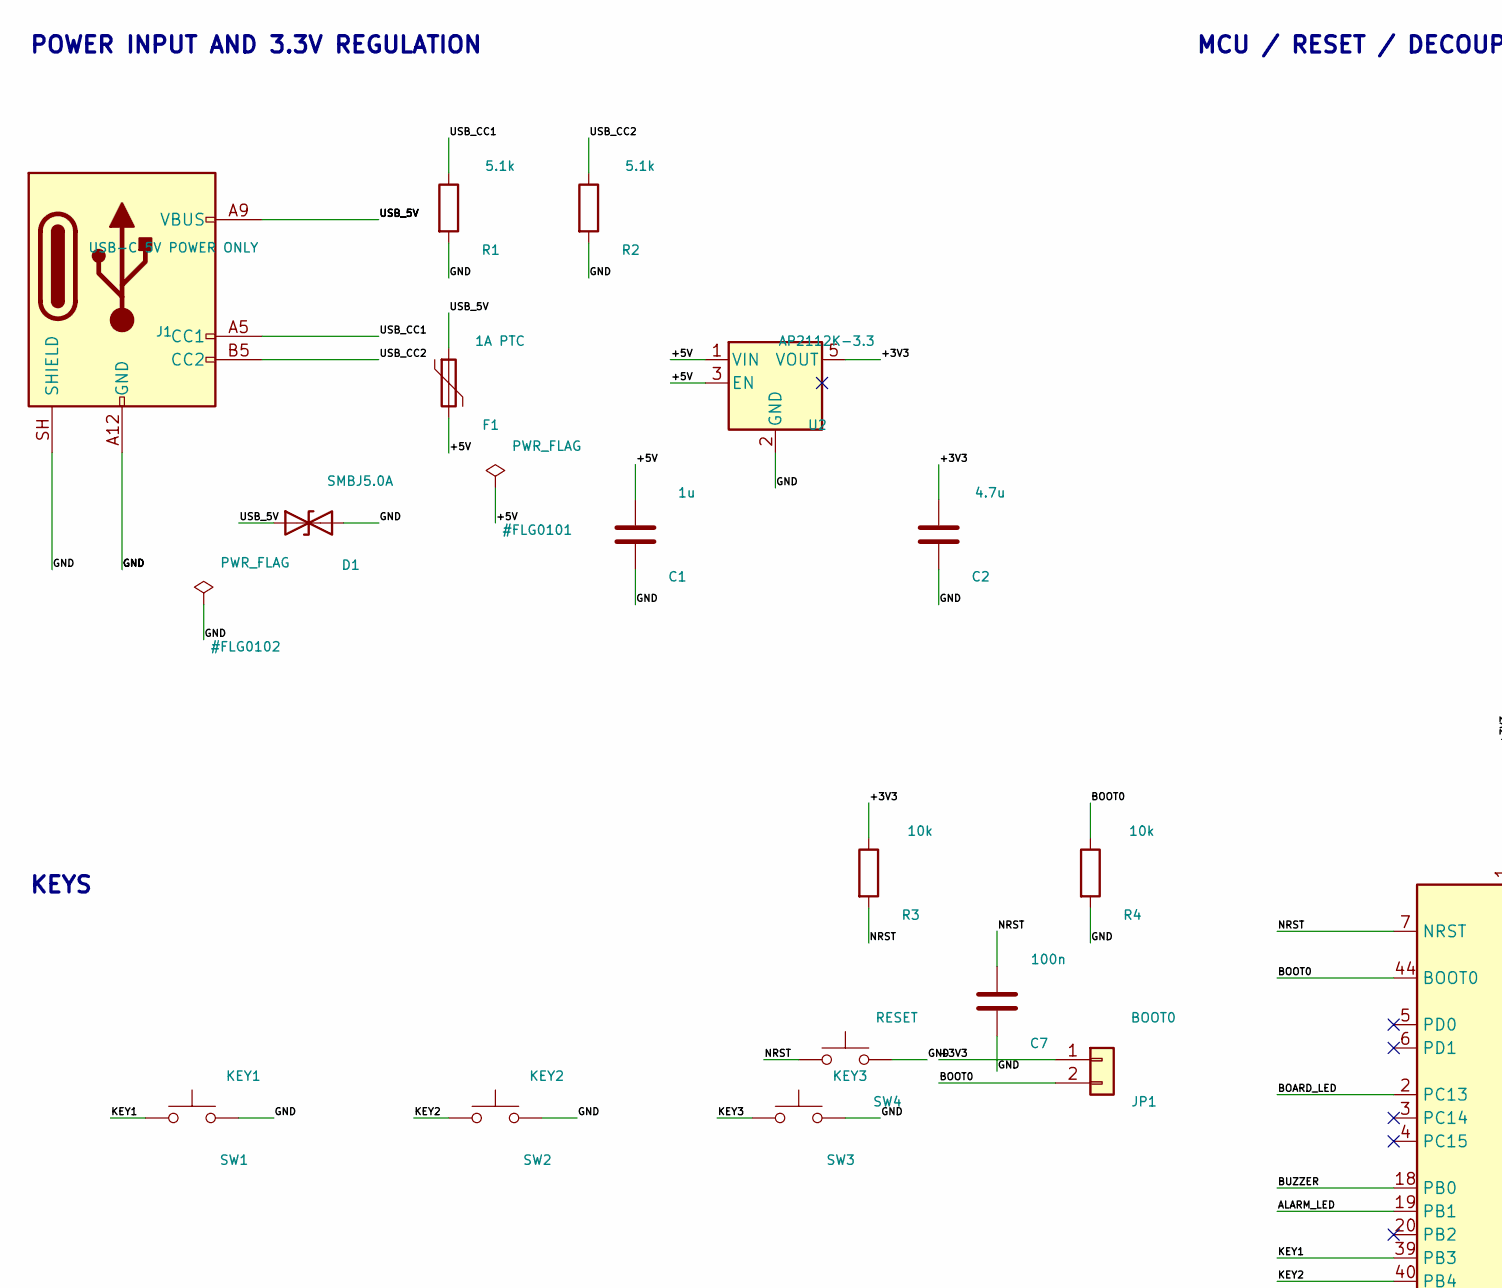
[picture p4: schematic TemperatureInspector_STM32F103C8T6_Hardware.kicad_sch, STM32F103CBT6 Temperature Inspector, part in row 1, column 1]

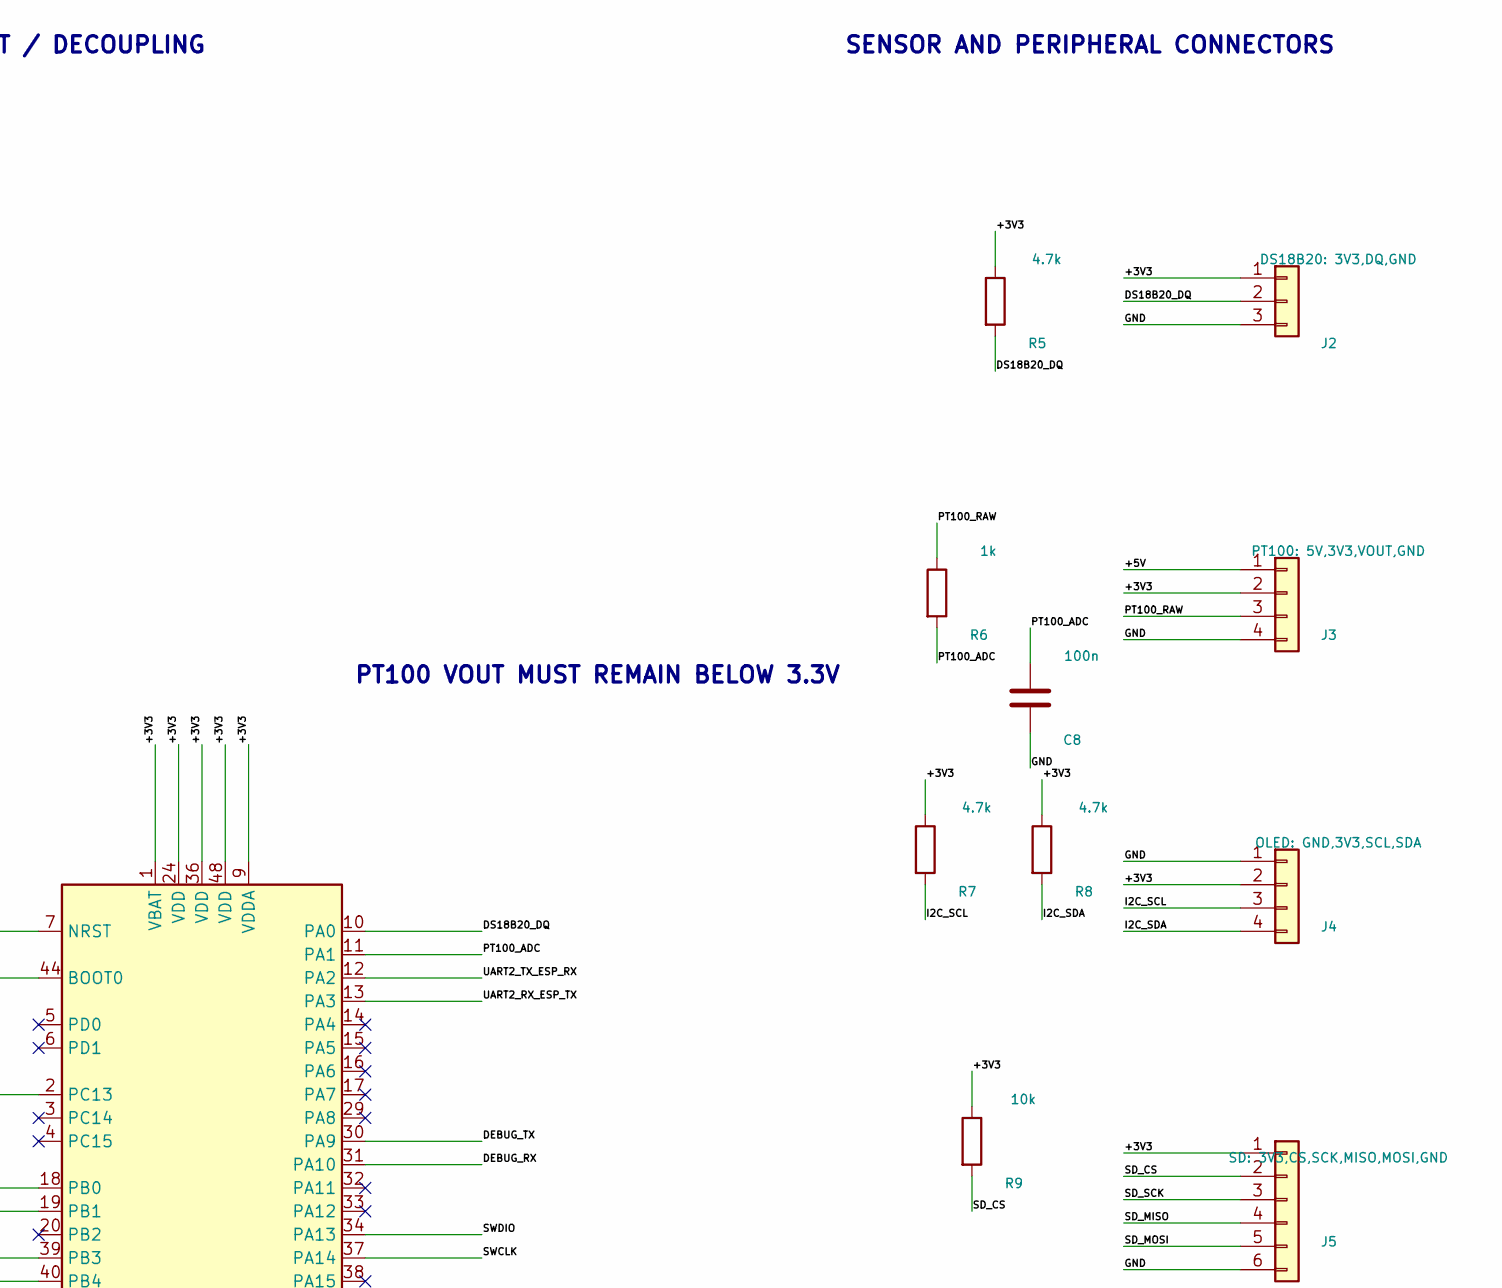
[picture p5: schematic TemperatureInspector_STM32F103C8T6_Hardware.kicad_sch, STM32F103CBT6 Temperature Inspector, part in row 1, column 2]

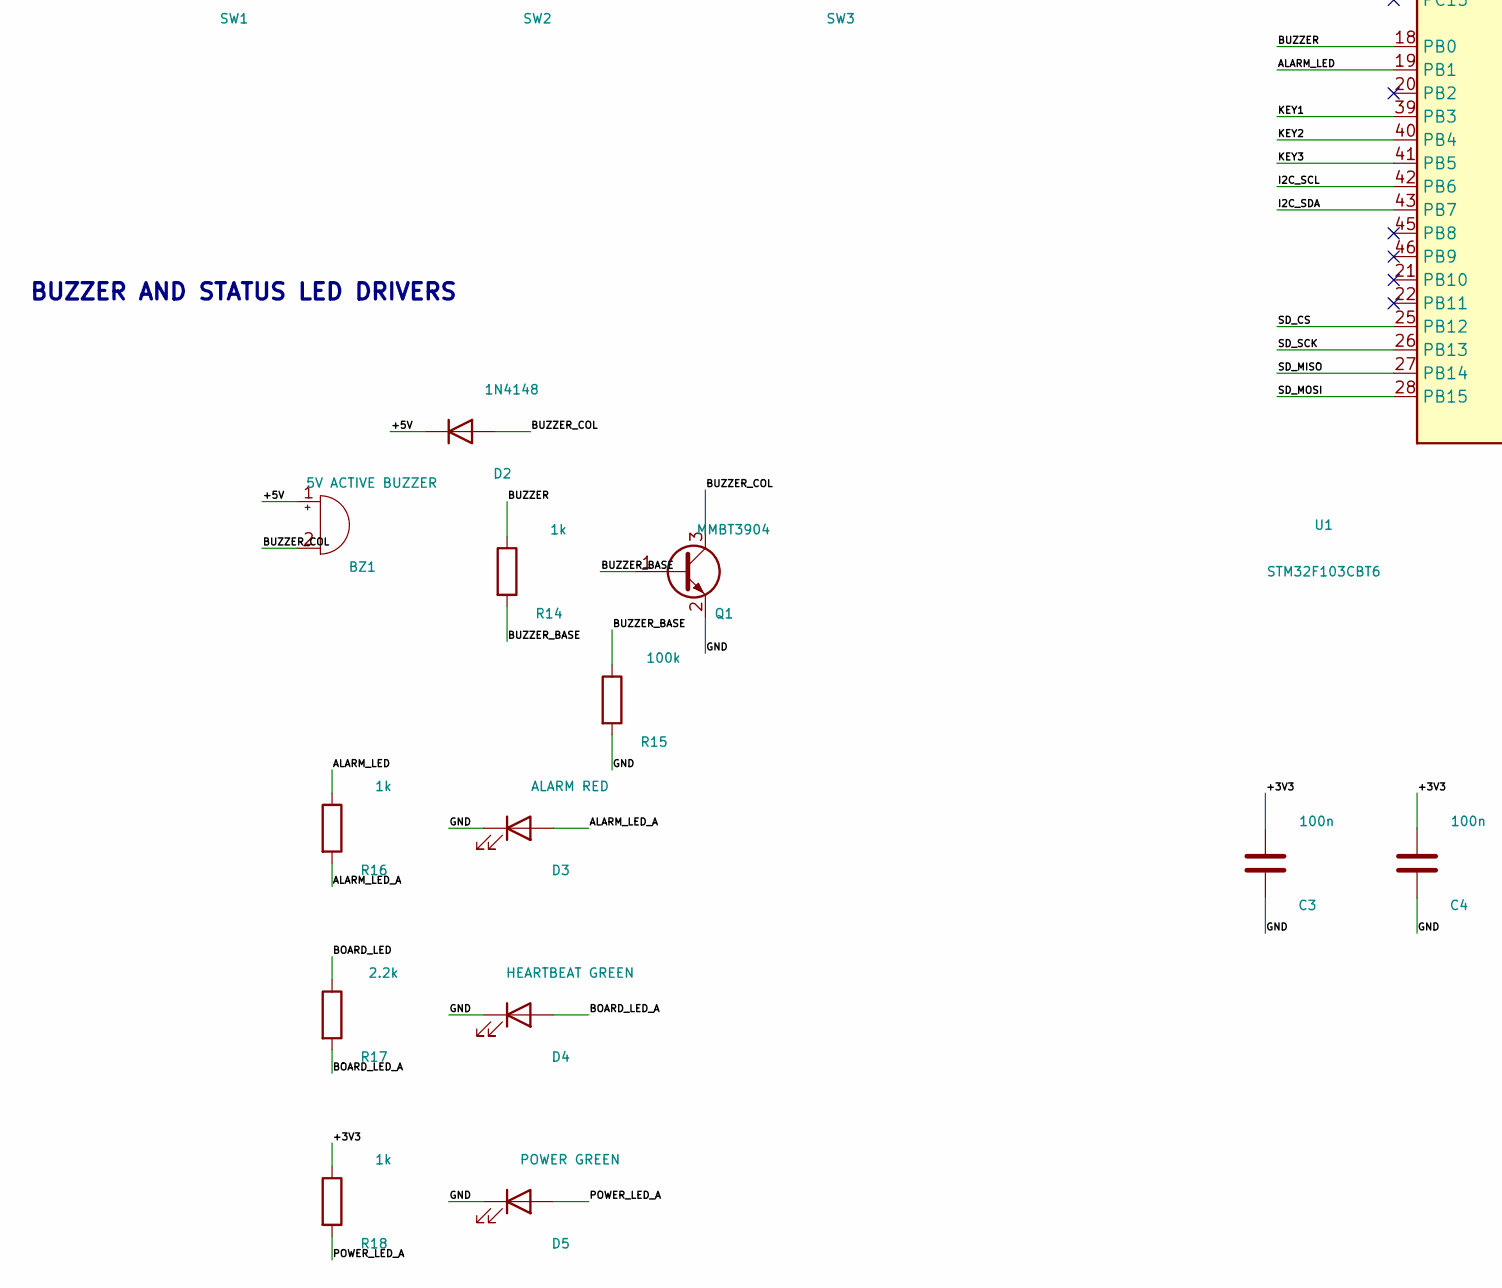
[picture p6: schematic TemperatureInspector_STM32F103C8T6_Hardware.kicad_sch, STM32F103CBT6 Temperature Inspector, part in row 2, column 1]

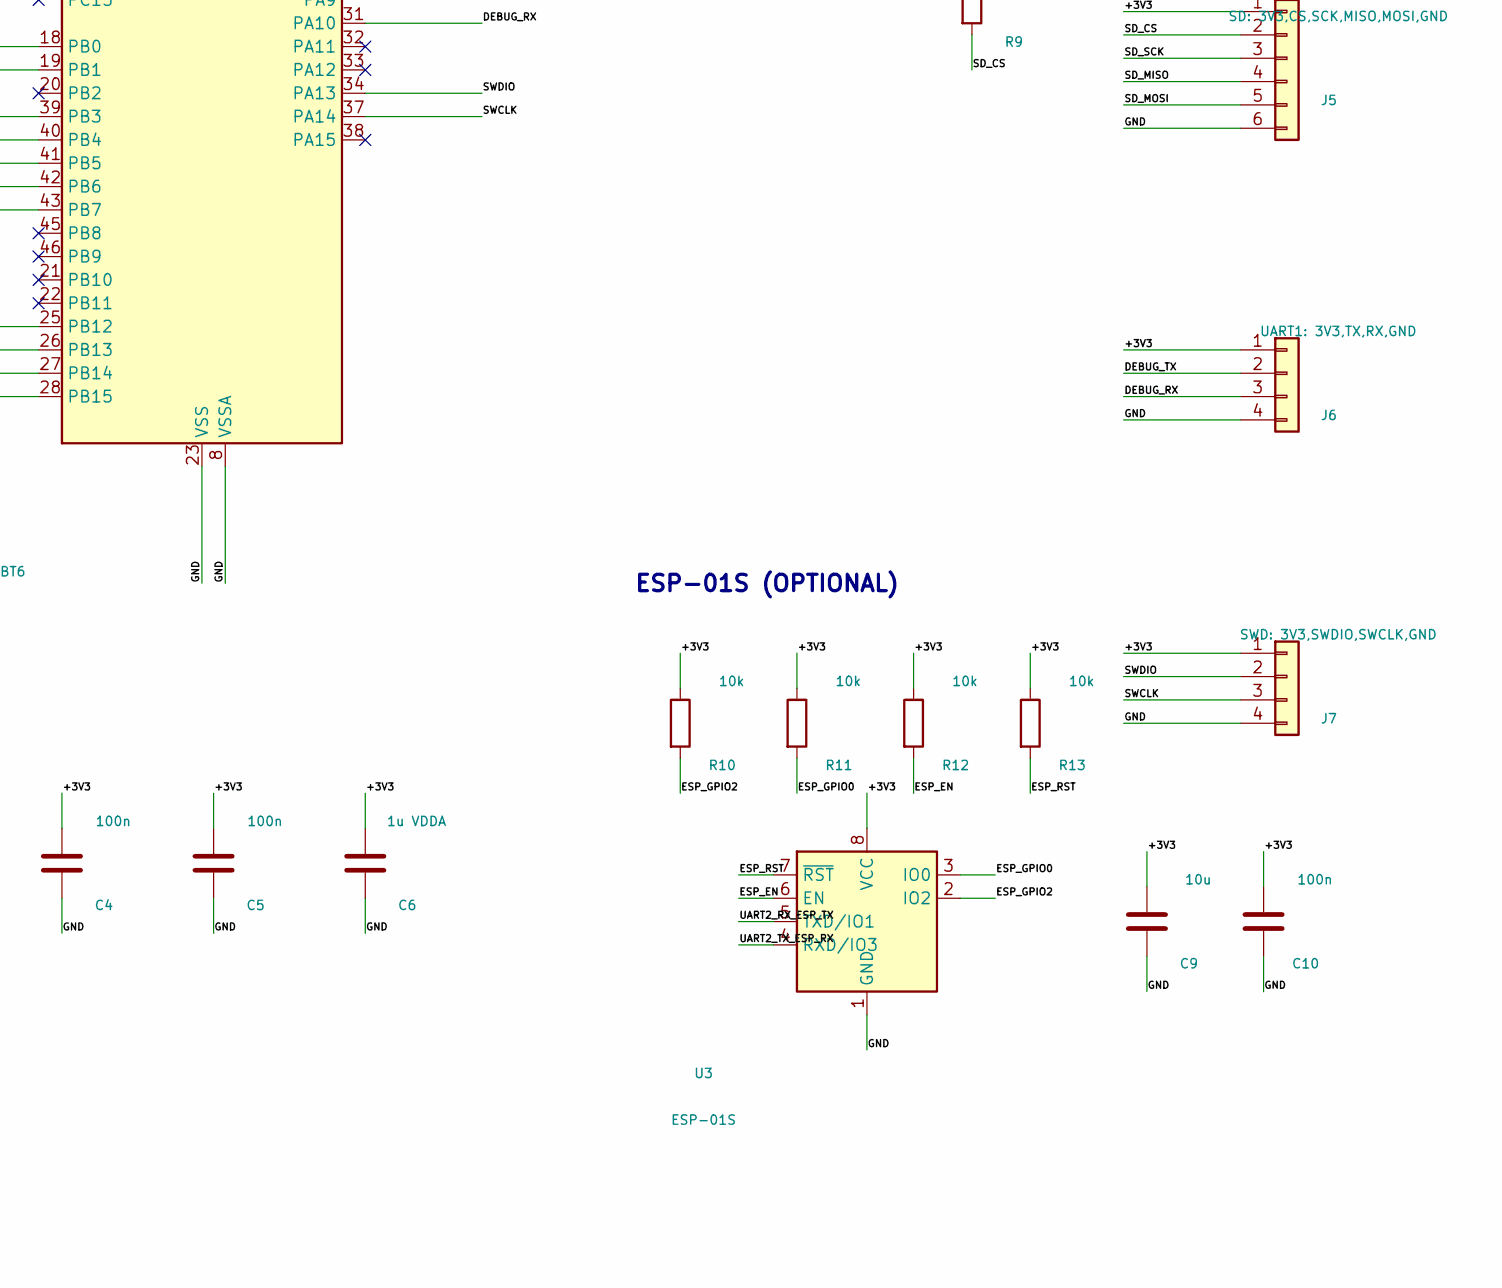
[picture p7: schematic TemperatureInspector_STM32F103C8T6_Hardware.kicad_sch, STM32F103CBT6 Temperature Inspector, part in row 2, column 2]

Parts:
BZ1: 5V ACTIVE BUZZER; Buzzer_12x9.5RM7.6
C1: 1u; C_0603_1608Metric
C2: 4.7u; C_0805_2012Metric
C3, C4, C5, C7, C8, C10: 100n; C_0603_1608Metric
C6: 1u VDDA; C_0603_1608Metric
C9: 10u; C_0805_2012Metric
D1: SMBJ5.0A; D_SMA
D2: 1N4148; D_SOD-123
D3: ALARM RED; LED_0603_1608Metric
D4: HEARTBEAT GREEN; LED_0603_1608Metric
D5: POWER GREEN; LED_0603_1608Metric
F1: 1A PTC; Fuse_1206_3216Metric
J1: USB-C 5V POWER ONLY; USB_C_Receptacle_GCT_USB4125-xx-x_6P_TopMnt_Horizontal
J2: DS18B20: 3V3,DQ,GND; PinHeader_1x03_P2.54mm_Vertical
J3: PT100: 5V,3V3,VOUT,GND; PinHeader_1x04_P2.54mm_Vertical
J4: OLED: GND,3V3,SCL,SDA; PinHeader_1x04_P2.54mm_Vertical
J5: SD: 3V3,CS,SCK,MISO,MOSI,GND; PinHeader_1x06_P2.54mm_Vertical
J6: UART1: 3V3,TX,RX,GND; PinHeader_1x04_P2.54mm_Vertical
J7: SWD: 3V3,SWDIO,SWCLK,GND; PinHeader_1x04_P2.54mm_Vertical
JP1: BOOT0; PinHeader_1x02_P2.54mm_Vertical
Q1: MMBT3904; SOT-23
R1, R2: 5.1k; R_0603_1608Metric
R3, R4, R9, R10, R11, R12, R13: 10k; R_0603_1608Metric
R5, R7, R8: 4.7k; R_0603_1608Metric
R6, R14, R16, R18: 1k; R_0603_1608Metric
R15: 100k; R_0603_1608Metric
R17: 2.2k; R_0603_1608Metric
SW1: KEY1; SW_PUSH_6mm
SW2: KEY2; SW_PUSH_6mm
SW3: KEY3; SW_PUSH_6mm
SW4: RESET; SW_PUSH_6mm
U1: STM32F103CBT6; LQFP-48_7x7mm_P0.5mm
U2: AP2112K-3.3; SOT-23-5
U3: ESP-01S; ESP-01

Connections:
/+3V3: C2.1, C3.1, C4.1, C5.1, C6.1, C9.1, C10.1, J2.1, J3.2, J4.2, J5.1, J6.1, J7.1, JP1.1, R3.1, R5.1, R7.1, R8.1, R9.1, R10.1, R11.1, R12.1, R13.1, R18.1, U1.1 (VBAT), U1.9 (VDDA), U1.24 (VDD), U1.36 (VDD), U1.48 (VDD), U2.5 (VOUT), U3.8 (VCC)
/+5V: BZ1.1 (+), C1.1, D2.1 (K), F1.2, J3.1, U2.1 (VIN), U2.3 (EN)
/ALARM_LED: R16.1, U1.19 (PB1)
/ALARM_LED_A: D3.2 (A), R16.2
/BOARD_LED: R17.1, U1.2 (PC13)
/BOARD_LED_A: D4.2 (A), R17.2
/BOOT0: JP1.2, R4.1, U1.44 (BOOT0)
/BUZZER: R14.1, U1.18 (PB0)
/BUZZER_BASE: Q1.1 (B), R14.2, R15.1
/BUZZER_COL: BZ1.2 (-), D2.2 (A), Q1.3 (C)
/DEBUG_RX: J6.3, U1.31 (PA10)
/DEBUG_TX: J6.2, U1.30 (PA9)
/DS18B20_DQ: J2.2, R5.2, U1.10 (PA0)
/ESP_EN: R12.2, U3.6 (EN)
/ESP_GPIO0: R11.2, U3.3 (IO0)
/ESP_GPIO2: R10.2, U3.2 (IO2)
/ESP_RST: R13.2, U3.7 (~RST)
/GND: C1.2, C2.2, C3.2, C4.2, C5.2, C6.2, C7.2, C8.2, C9.2, C10.2, D1.2 (A2), D3.1 (K), D4.1 (K), D5.1 (K), J1.A12 (GND), J1.B12 (GND), J1.SH (SHIELD), J2.3, J3.4, J4.1, J5.6, J6.4, J7.4, Q1.2 (E), R1.2, R2.2, R4.2, R15.2, SW1.2, SW2.2, SW3.2, SW4.2, U1.8 (VSSA), U1.23 (VSS), U1.35 (VSS), U1.47 (VSS), U2.2 (GND), U3.1 (GND)
/I2C_SCL: J4.3, R7.2, U1.42 (PB6)
/I2C_SDA: J4.4, R8.2, U1.43 (PB7)
/KEY1: SW1.1, U1.39 (PB3)
/KEY2: SW2.1, U1.40 (PB4)
/KEY3: SW3.1, U1.41 (PB5)
/NRST: C7.1, R3.2, SW4.1, U1.7 (NRST)
/POWER_LED_A: D5.2 (A), R18.2
/PT100_ADC: C8.1, R6.2, U1.11 (PA1)
/PT100_RAW: J3.3, R6.1
/SD_CS: J5.2, R9.2, U1.25 (PB12)
/SD_MISO: J5.4, U1.27 (PB14)
/SD_MOSI: J5.5, U1.28 (PB15)
/SD_SCK: J5.3, U1.26 (PB13)
/SWCLK: J7.3, U1.37 (PA14)
/SWDIO: J7.2, U1.34 (PA13)
/UART2_RX_ESP_TX: U1.13 (PA3), U3.5 (TXD/IO1)
/UART2_TX_ESP_RX: U1.12 (PA2), U3.4 (RXD/IO3)
/USB_5V: D1.1 (A1), F1.1, J1.A9 (VBUS), J1.B9 (VBUS)
/USB_CC1: J1.A5 (CC1), R1.1
/USB_CC2: J1.B5 (CC2), R2.1

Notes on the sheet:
POWER INPUT AND 3.3V REGULATION
BUZZER AND STATUS LED DRIVERS
KEYS
PT100 VOUT MUST REMAIN BELOW 3.3V
SENSOR AND PERIPHERAL CONNECTORS
MCU / RESET / DECOUPLING
ESP-01S (OPTIONAL)

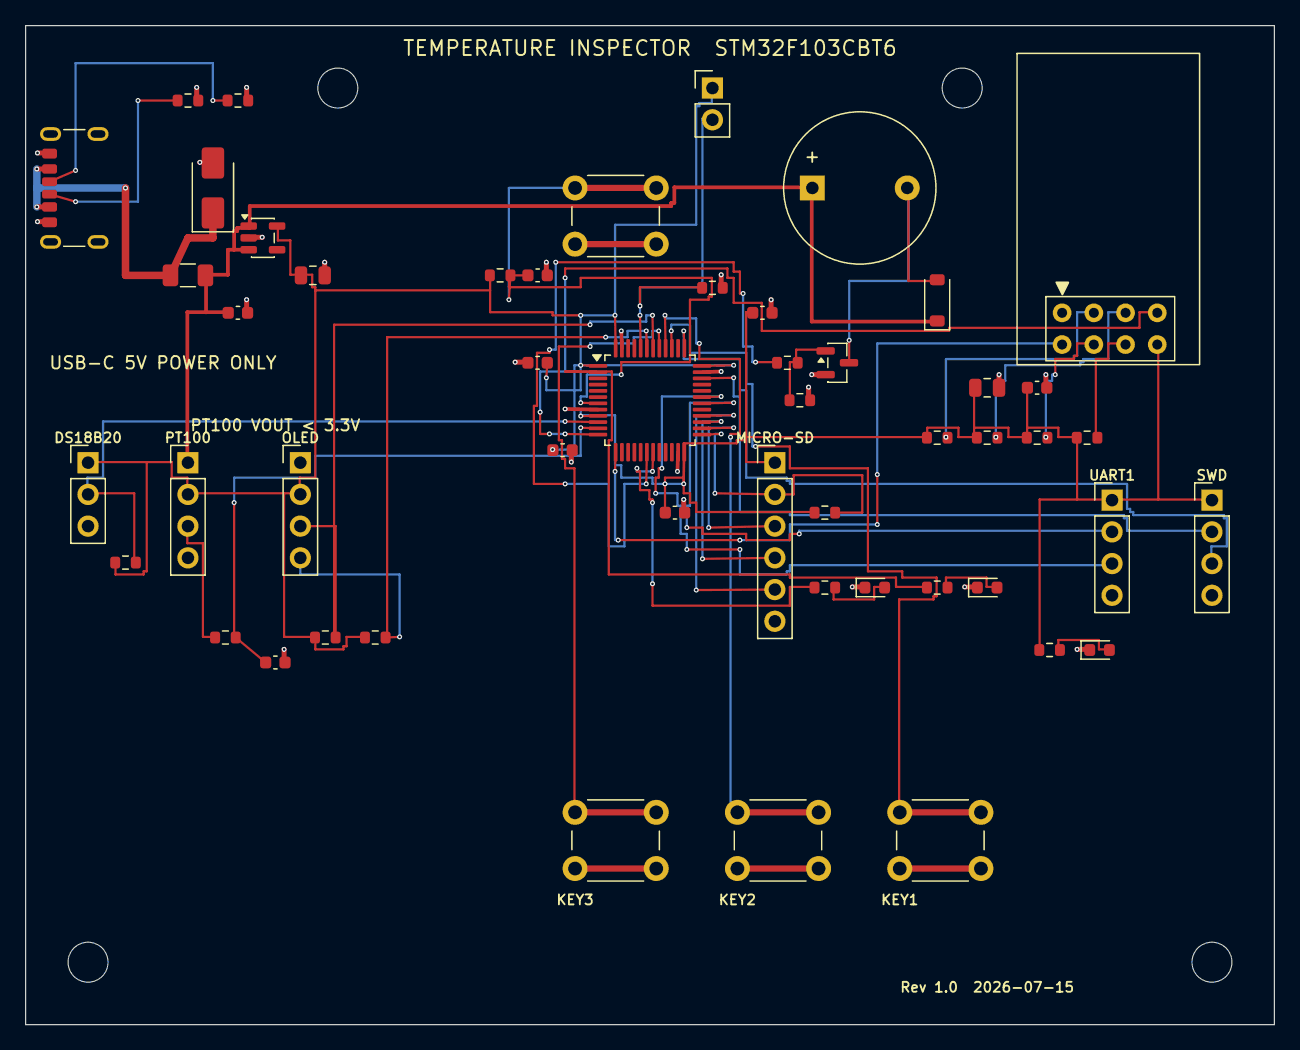
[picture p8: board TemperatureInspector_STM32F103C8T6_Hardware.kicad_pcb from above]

Board: 4 copper layers, 100.0 x 80.0 mm, 55 parts (0 on the bottom side), 38 nets.

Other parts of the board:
H1, H2, H3, H4: M3; MountingHole_3.2mm_M3

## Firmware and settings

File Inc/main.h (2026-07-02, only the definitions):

#define BOARD_LED_Pin GPIO_PIN_13
#define BOARD_LED_GPIO_Port GPIOC
#define DS18B20_DQ_Pin GPIO_PIN_0
#define DS18B20_DQ_GPIO_Port GPIOA
#define BUZZER_Pin GPIO_PIN_0
#define BUZZER_GPIO_Port GPIOB
#define ALARM_LED_Pin GPIO_PIN_1
#define ALARM_LED_GPIO_Port GPIOB
#define SD_CS_Pin GPIO_PIN_12
#define SD_CS_GPIO_Port GPIOB
#define KEY1_Pin GPIO_PIN_3
#define KEY1_GPIO_Port GPIOB
#define KEY2_Pin GPIO_PIN_4
#define KEY2_GPIO_Port GPIOB
#define KEY3_Pin GPIO_PIN_5
#define KEY3_GPIO_Port GPIOB

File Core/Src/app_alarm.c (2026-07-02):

#include "app_alarm.h"
#include "app_config.h"

/* 直接控制报警灯和蜂鸣器，高电平有效。 */
void Alarm_Set(uint8_t enabled)
{
    HAL_GPIO_WritePin(ALARM_LED_PORT, ALARM_LED_PIN, enabled ? GPIO_PIN_SET : GPIO_PIN_RESET);
    HAL_GPIO_WritePin(BUZZER_PORT, BUZZER_PIN, enabled ? GPIO_PIN_SET : GPIO_PIN_RESET);
}

/* 报警节奏任务：报警有效时每 300ms 翻转一次，实现闪灯/间歇蜂鸣。 */
void Alarm_Task(uint8_t enabled)
{
    static uint32_t last_toggle = 0;
    static uint8_t state = 0;

    if (!enabled)
    {
        state = 0;
        Alarm_Set(0);
        return;
    }

    if ((HAL_GetTick() - last_toggle) >= 200U)
    {
        state ^= 1U;
        Alarm_Set(state);
        last_toggle = HAL_GetTick();
    }
}

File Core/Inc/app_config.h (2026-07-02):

#ifndef APP_CONFIG_H
#define APP_CONFIG_H

#include "stm32f1xx_hal.h"

/* DS18B20 单总线温度传感器引脚，外部需要 4.7k 上拉到 3.3V。 */
#define DS18B20_PORT GPIOA
#define DS18B20_PIN  GPIO_PIN_0

/* 三个按键均为低电平按下，GPIO 内部上拉。 */
#define KEY1_PORT GPIOB
#define KEY1_PIN  GPIO_PIN_3
#define KEY2_PORT GPIOB
#define KEY2_PIN  GPIO_PIN_4
#define KEY3_PORT GPIOB
#define KEY3_PIN  GPIO_PIN_5

/* 声光报警输出：高电平有效。 */
#define BUZZER_PORT GPIOB
#define BUZZER_PIN  GPIO_PIN_0
#define ALARM_LED_PORT GPIOB
#define ALARM_LED_PIN  GPIO_PIN_1
#define BOARD_LED_PORT GPIOC
#define BOARD_LED_PIN  GPIO_PIN_13

/* SD 卡 SPI2 片选引脚，SCK/MISO/MOSI 在 main.c 中配置为 PB13/PB14/PB15。 */
#define SD_CS_PORT GPIOB
#define SD_CS_PIN  GPIO_PIN_12

/* 主要运行周期配置。 */
#define OLED_I2C_ADDR       (0x3C << 1)
#define SAMPLE_PERIOD_MS    15000U
#define DISPLAY_PERIOD_MS   500U
#define LOG_PERIOD_MS       15000U
#define WIFI_PERIOD_MS      15000U

/* 云服务默认关闭；打开前需要先填写下方 WiFi 和 OneNET 参数。 */
#define APP_ENABLE_WIFI      0

/* 连续多少次超阈值才真正报警，用来减少偶发抖动导致的误报警。 */
#define ALARM_CONFIRM_COUNT  2U

#define APP_ENABLE_FATFS     1

/* 默认阈值；按键或串口修改后会保存到内部 Flash。 */
#define DS18B20_LOW_DEFAULT_C   10.0f
#define DS18B20_HIGH_DEFAULT_C  60.0f
#define PT100_LOW_DEFAULT_C      0.0f
#define PT100_HIGH_DEFAULT_C   100.0f
#define TEMP_STEP_C          1.0f

/* PT100 模块按用户给出的关系式换算：温度 = 51.2 * ADC 电压。 */
#define PT100_ADC_VREF       3.3f
#define PT100_ADC_MAX        4095.0f
#define PT100_TEMP_PER_VOLT  51.2f

/* ESP-01S/OneNET 参数占位；开启云服务时再填写。 */
#define WIFI_SSID            "YOUR_WIFI_SSID"
#define WIFI_PASSWORD        "YOUR_WIFI_PASSWORD"
#define ONENET_MQTT_HOST     "mqtts.heclouds.com"
#define ONENET_MQTT_PORT     1883
#define ONENET_MQTT_PORT_STR "1883"
#define ONENET_PRODUCT_ID    "YOUR_PRODUCT_ID"
#define ONENET_DEVICE_NAME   "YOUR_DEVICE_NAME"
#define ONENET_DEVICE_TOKEN  "YOUR_DEVICE_TOKEN"

#endif

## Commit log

2026-07-02 Initial STM32 temperature inspector project
2026-07-16 Add KiCad hardware design and manufacturing files
    [BOM.csv, Component_Positions_All.csv, PickPlace_SMD.csv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]

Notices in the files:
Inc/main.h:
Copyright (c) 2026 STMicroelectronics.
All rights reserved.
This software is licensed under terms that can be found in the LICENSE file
